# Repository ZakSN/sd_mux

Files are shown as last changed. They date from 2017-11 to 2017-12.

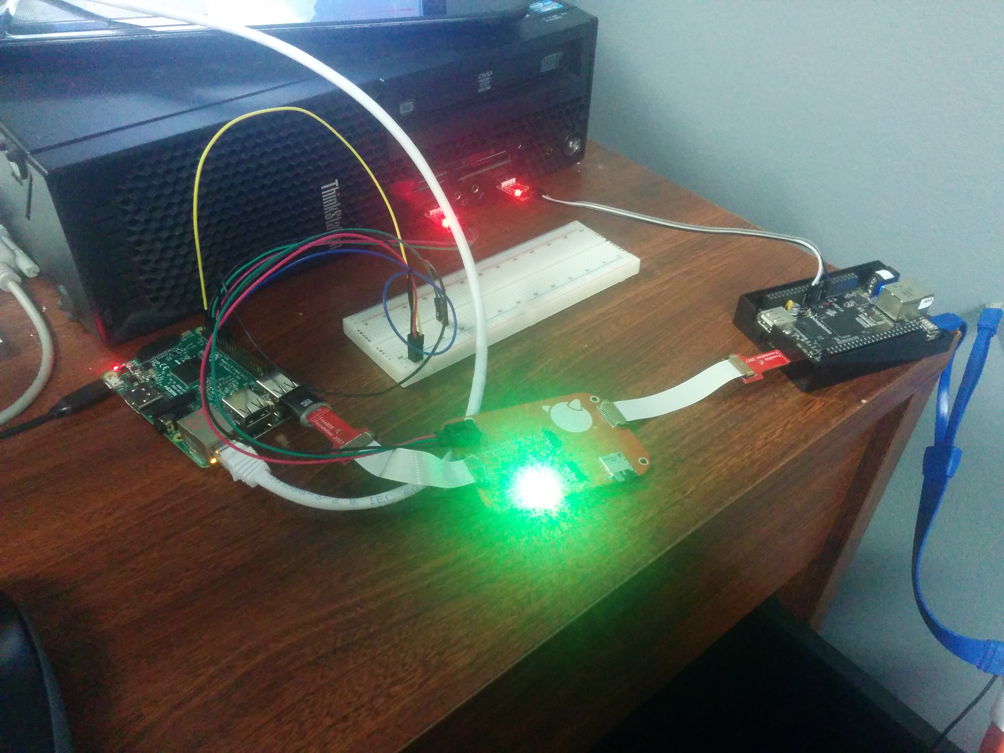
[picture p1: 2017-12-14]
docs/photos/demo_setup.jpg

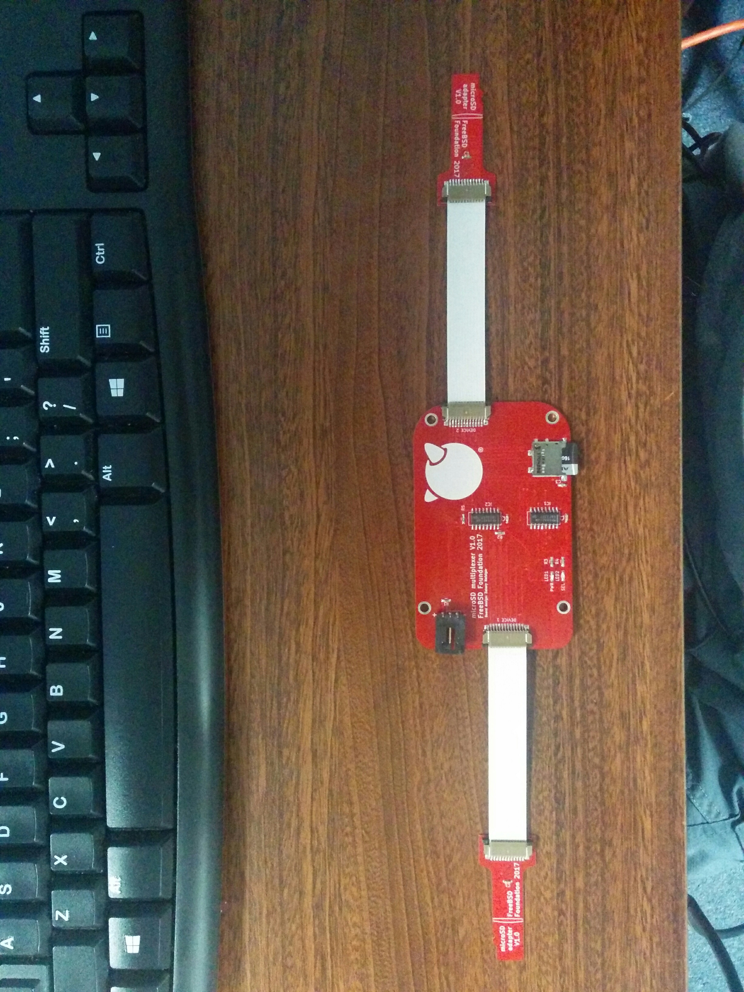
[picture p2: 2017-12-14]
docs/photos/completed_unit.jpg

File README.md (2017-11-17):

## micro SD card multiplexer
This project is a simple micro SD card multiplexer for single board computers
such as the Raspberry Pi. The device will be used for testing of FreeBSD on 
a variety of SBCs. The idea is that a host computer can be used to flash an
image to the SD card and the target computer can then be booted from the SD 
card without the need to manually move the SD card from one computer to the 
other. The device consists of three boards: 

1. The multiplexer board, which is controlled by the host and holds the micro
SD card being used.
2. Two micro SD card plug boards. The are PCBs the smae shape as a micro SD 
card one of these boards plugs into the host and the other plugs into the 
target. the plug boards are connected to the mux board via flat flex cables
allowing them to be physicaly seperate from the mux board.

The device is loosely inspired by a similar project found here: 
<http://www.linuxinternals.org/blog/2014/06/04/a-microsd-card-remote-switcher/>

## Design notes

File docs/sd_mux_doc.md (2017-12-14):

# microSD Multiplexer

## Introduction:
This repository contains designs for a simple SD Card multiplexer. Many single board computers (i.e. Raspberry Pi, BeagleBone, Pine64, etc) boot from a microSD card, in a test environment this can be somewhat inconvenient since flashing a new boot image requires physically transferring the microSD card from the board under test to a host computer. This device allows a microSD card to be swapped from one device to another without ever being physically moved. The advantage of this method over alternatives such as network booting is that this method allows the entire boot process to be verified.

## `sd_mux` Board
The `sd_mux` board provides the multiplexer functionality of the device. It uses two SN74CBT3257 4x2:1 mux/demux chips to switch the microSD card's pins from one device to another. The board provides a microSD card slot for the card being switched. The multiplexer outputs are broken out to two flat flex connectors (`device 1` and `decive 2` on the silkscreen). Select and power lines for the multiplexers are provided by a 3 pin header (center select). Power is 5VDC and select is 5V TTL. There are two LEDs: `PWR` and `SEL`. `PWR` is lit when the board is receiving power. `SEL` is lit when `device 2` is attached to the SD card. VDD for the SD card itself is switched through the multiplexer. The board is the same form factor as a BeagleBone Black.

The SN74CBT3257 doesn't seem to be able to handle higher speed microSD cards. UHS class 1 cards seem to work reliably whereas UHS class 3 cards occasionally behave badly.

## `sd_plug` Board
The `sd_plug` board is the same shape as a microSD card and provides a physical connection to a device's microSD card slot. The `sd_plug` board provides footprints for two flat flax connectors, one on the top and one on the bottom. This allows the board to be plugged in either side up without having to twist the flat flex cable. The thickness of the `sd_plug` board is a critical dimension since it must fit into a microSD card slot. A 'half-thickness' ~0.75mm (30mil) board works well.

## `switcher`
`switcher` is a shell script that switches the device the microSD card is attached to. The script runs on the host and uses one of the host's gpio pins to select whether the microSD card is attached to the host or the target. The script is intended to run in a Raspberry Pi B model 3, but could be adapted to a different host computer.

## Components
The following components were used:

- SN74CBT3257 4x2:1 mux/demux chip
- 1040310811 push/pull microSD card socket (same as Raspberry Pi)
- SFW12R-2STE1LF 12 position flat flex connector
- 150060RS75000 and  150060GS75000 red and green 0603 LEDs
- 0603 passives: 0.1uF capacitors, 1Kohm and 10Kohm resistors

## Additional resources
- SN74CBT3257 datasheet: <http://www.ti.com/lit/ds/symlink/sn74cbt3257.pdf>
- microSD card mechanical and electrical specification: <http://www.farnell.com/datasheets/1836582.pdf>

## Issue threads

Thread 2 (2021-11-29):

Improving the board

gipi, 2021-11-29:
As indicated in the documentation, the ``SN74CBT3257`` is not able to handle card with higher speed capabilities, for this reason I modified it in order to use the ``SN74CB3Q3257`` that is a **high-bandwidth bus switch**. I ordered PCBs with the modification and it works like a charm (I didn't test extensively but a card that didn't work for the old board works with this one).

Are you interested in the modification? Could be interesting to extend the functionality of the board to support also USB stick or similar.

mfaccin, 2022-05-26:
awesome @gipi! thank you and IMHO would be nice if you could share the project too.

gipi, 2022-05-26:
here the branch https://github.com/gipi/sd_mux/tree/SN74CB3Q3257 ; let me know if you see something wrong.

Just a couple of notes: the new chip has a smaller footprint, it needs 3v3 (hence the added voltage regulator) and I added  a footprint for a USB connector but I didn't test it. I also added a ground plane (I'm not an electrical engineer but usually it's a good thing to add). Probably the traces should have length matching.

mfaccin, 2022-05-26:
@gipi I can take a look, sure. Could you check if you updated the files into the last commit? It looks like the same here.

gipi, 2022-05-26:
you have to use the branch ``SN74CB3Q3257``, you can see the difference here https://github.com/gipi/sd_mux/commit/2620ef97afc16683439ea1bfbc635598b7378978

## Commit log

2017-11-16 add schematic
    [sd_mux.sch]
2017-11-16 added some additional passives, fixed mistakes
    [sd_mux.sch]
2017-11-17 fix warnings, adjust component values
    [sd_mux.sch]
2017-11-17 rearranging project structure to include a second board
    [sd_mux.kicad_pcb, sd_mux.sch]
2017-11-17 added second board
    [sd_plug.kicad_pcb, sd_plug.sch]
2017-11-17 added readme, generated netlist
    [sd_mux.sch]
2017-11-20 first attempt at routing sd_mux
    [sd_mux.sch]
2017-11-21 redid the mux board in the same form factor as the beaglebone black, started work on sd plug board
    [sd_mux.kicad_pcb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]
2017-11-21 more work on the sd plug board
    [sd_plug.sch]
2017-11-22 adjustments to the sd plug board
    [sd_plug.sch]
2017-11-22 renumbered FFC on adapter board
    [sd_mux.kicad_pcb, sd_plug.kicad_pcb, sd_plug.sch]
2017-11-22 redid mounting holes on mux board
    [sd_mux.kicad_pcb, sd_plug.kicad_pcb]
2017-11-22 rerouted mux board to fix FFC flip issue and fix tracks that had become unalaigned from the grid
    [sd_mux.kicad_pcb, sd_mux.sch, sd_plug.kicad_pcb]
2017-11-23 finishing details on sd mux board
    [sd_mux.kicad_pcb]
2017-11-23 minor routing change to sd plug board
    [sd_plug.kicad_pcb]
2017-11-23 swapped SD card footprint
    [sd_mux.kicad_pcb, sd_plug.kicad_pcb]
2017-11-23 rerouted power line to avoid cut in ground plane
    [sd_mux.kicad_pcb]
2017-12-14 added script to control the mux
    [sd_mux.kicad_pcb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]
2017-12-15 cleaned up comments in switcher script
